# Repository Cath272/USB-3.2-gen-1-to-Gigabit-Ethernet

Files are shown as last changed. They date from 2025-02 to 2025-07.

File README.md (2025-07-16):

# USB 3.2 gen 1 to Gigabit Ethernet
 Gigabit Ethenet to USB C using VL162 and RTL8153

 ## VL162

  - 4:2 10Gbps USB Type-C Data Switch

  - Low power consumption with 6mW active at device mode

 ## RTL8153 

  - Integrated 10/100/1000M transceiver

  - Supports USB 3.0, 2.0, and 1.1

 ###  Built-in Voltage Regulators

- 5.0V to 3.3V LDO

- 3.3V to 1.2V Switching regulator

 ## TLV70233DBVR

 - 5V to 3.3V LDO for spi flash and leds

 ## W25Q16BVSSIG

 - 16Mbit SPI Flash  

 ## HR911130A
 - RJ45 Port with integrated magnetics 
 - 1000 Base-T Magnetics 

## PCB 
This board uses a 4 layer stackup with a  1.6mm thickness:

- POWER/SIGNAL

- GND
  
- GND
  
- POWER/SIGNAL

High Speed diferential lines need a refrence ground plane so internal planes are ground referance planes for the High speed USB lines

### Schematic:
Schematic
## PCB Screenshots

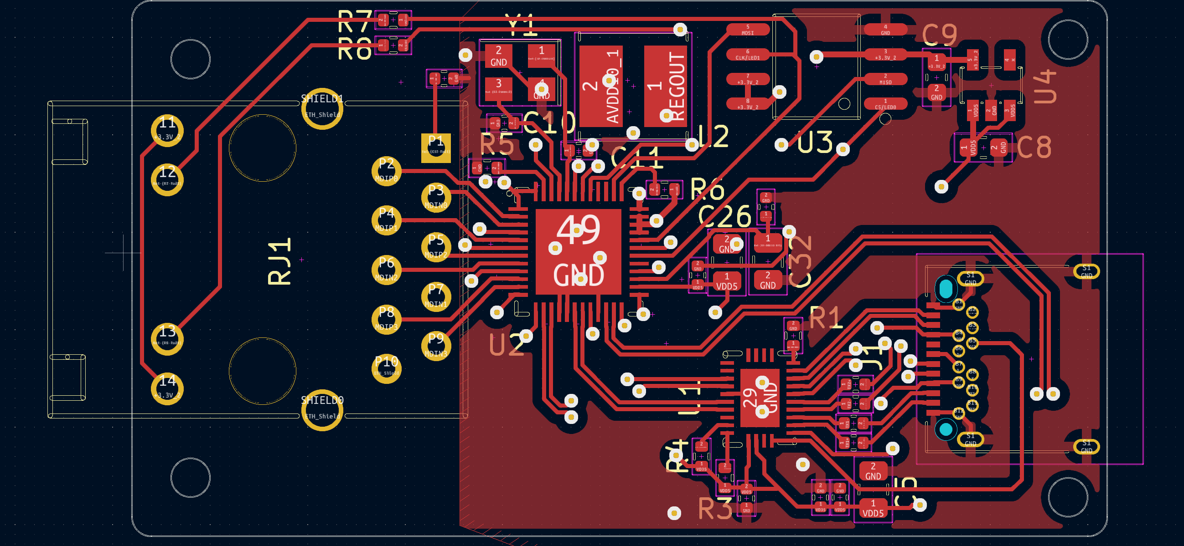
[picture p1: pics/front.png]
usb3ethfront

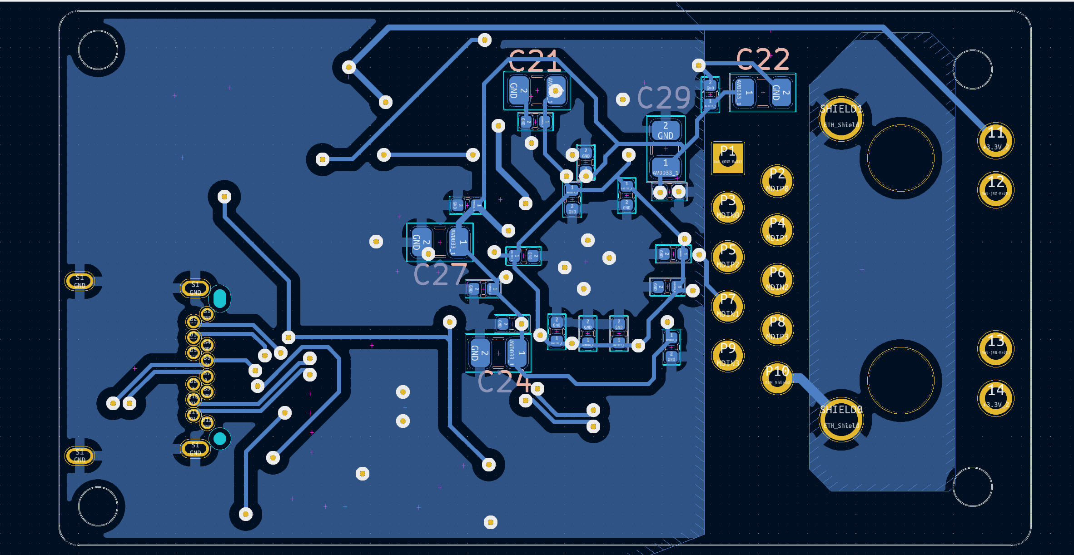
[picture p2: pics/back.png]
usb3ethback

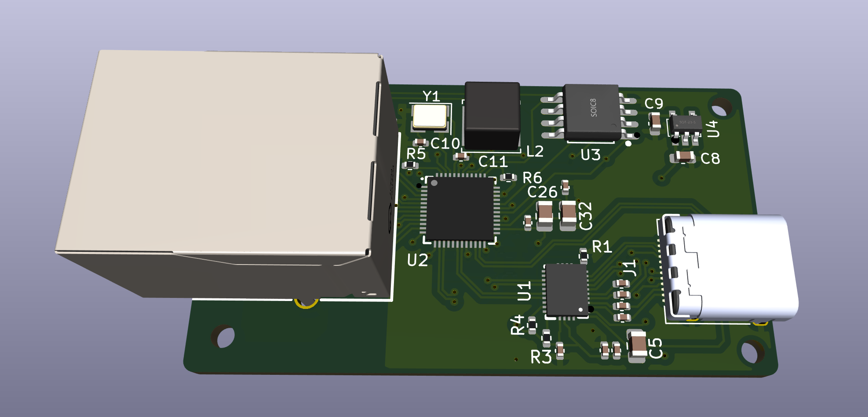
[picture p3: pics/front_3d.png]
usb3ethfront3d

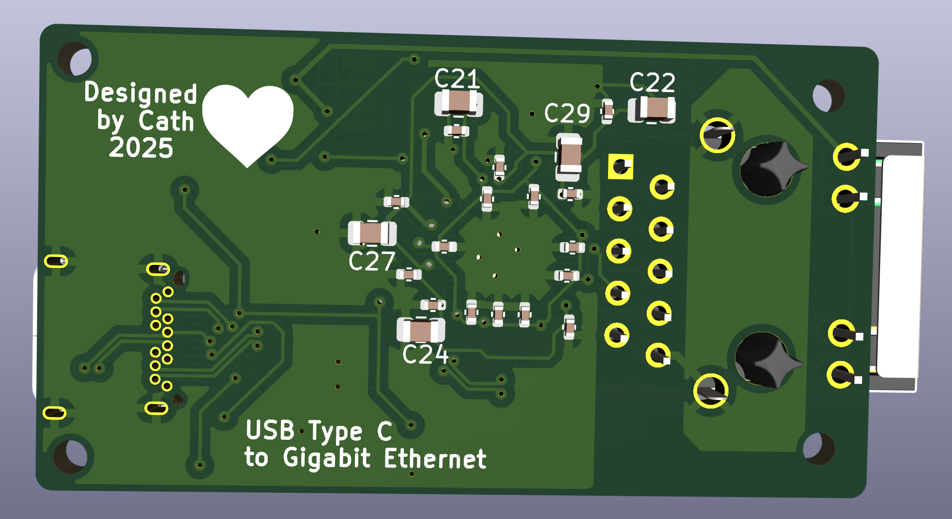
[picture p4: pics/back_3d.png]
usb3ethback3d


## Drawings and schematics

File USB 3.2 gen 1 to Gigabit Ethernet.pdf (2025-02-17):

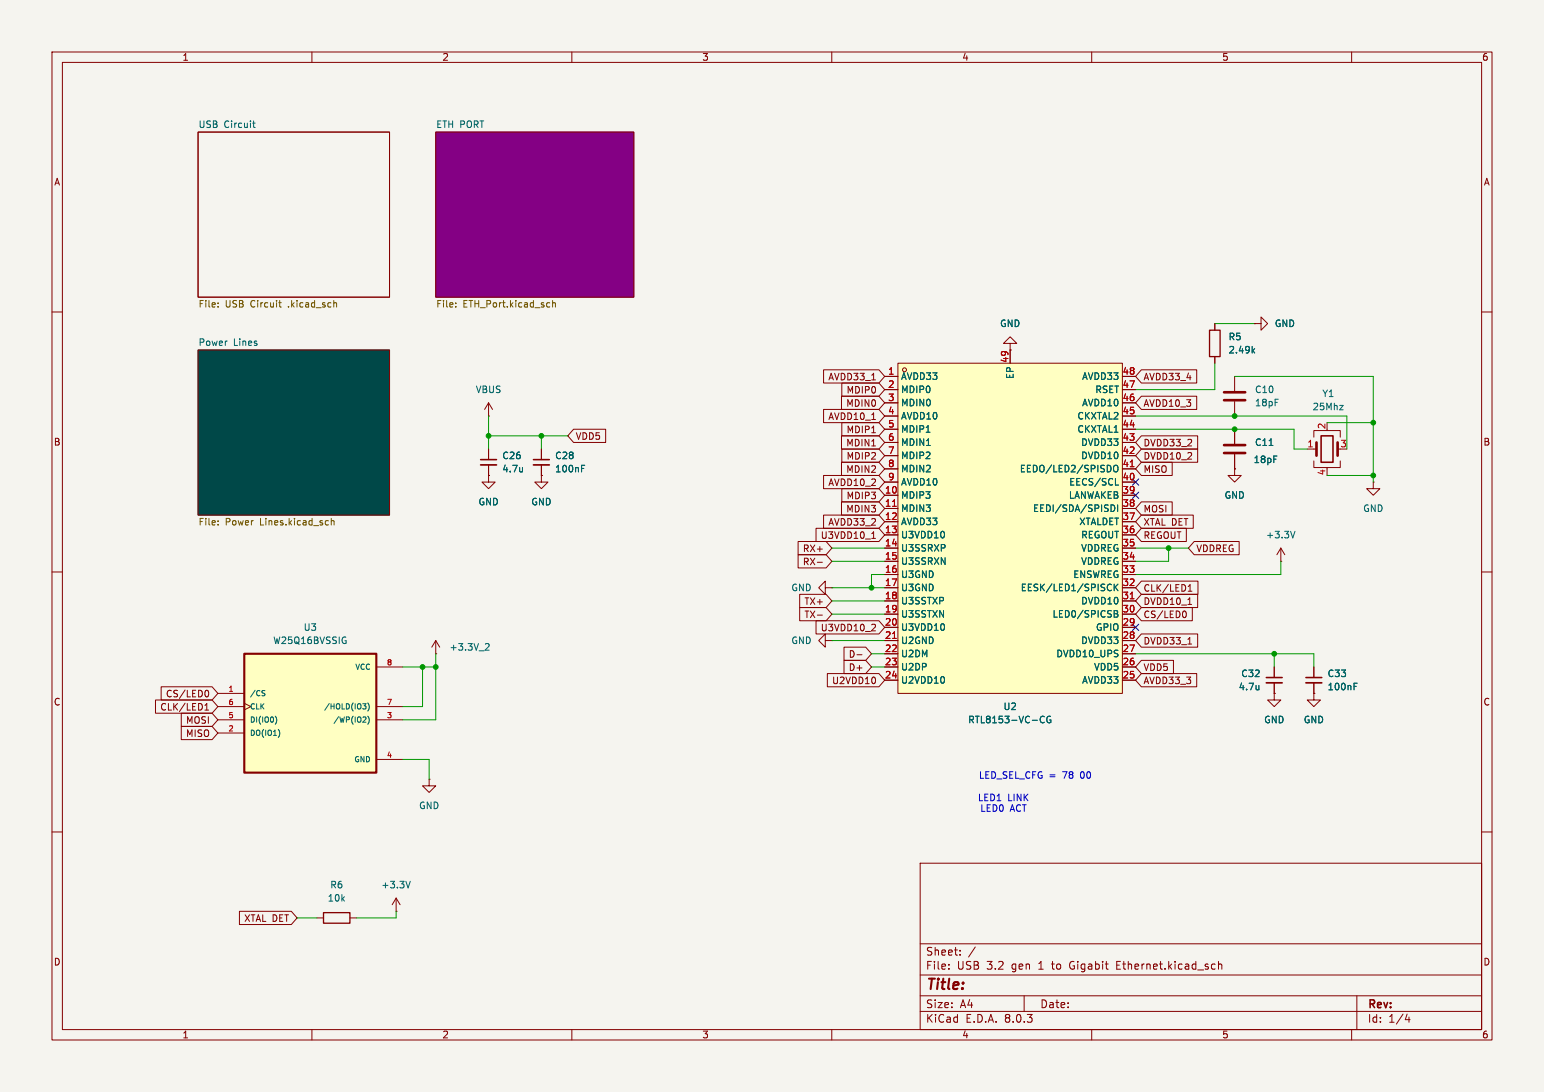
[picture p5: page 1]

AVDD33_4 VDD5 XTAL DET MOSI MISO

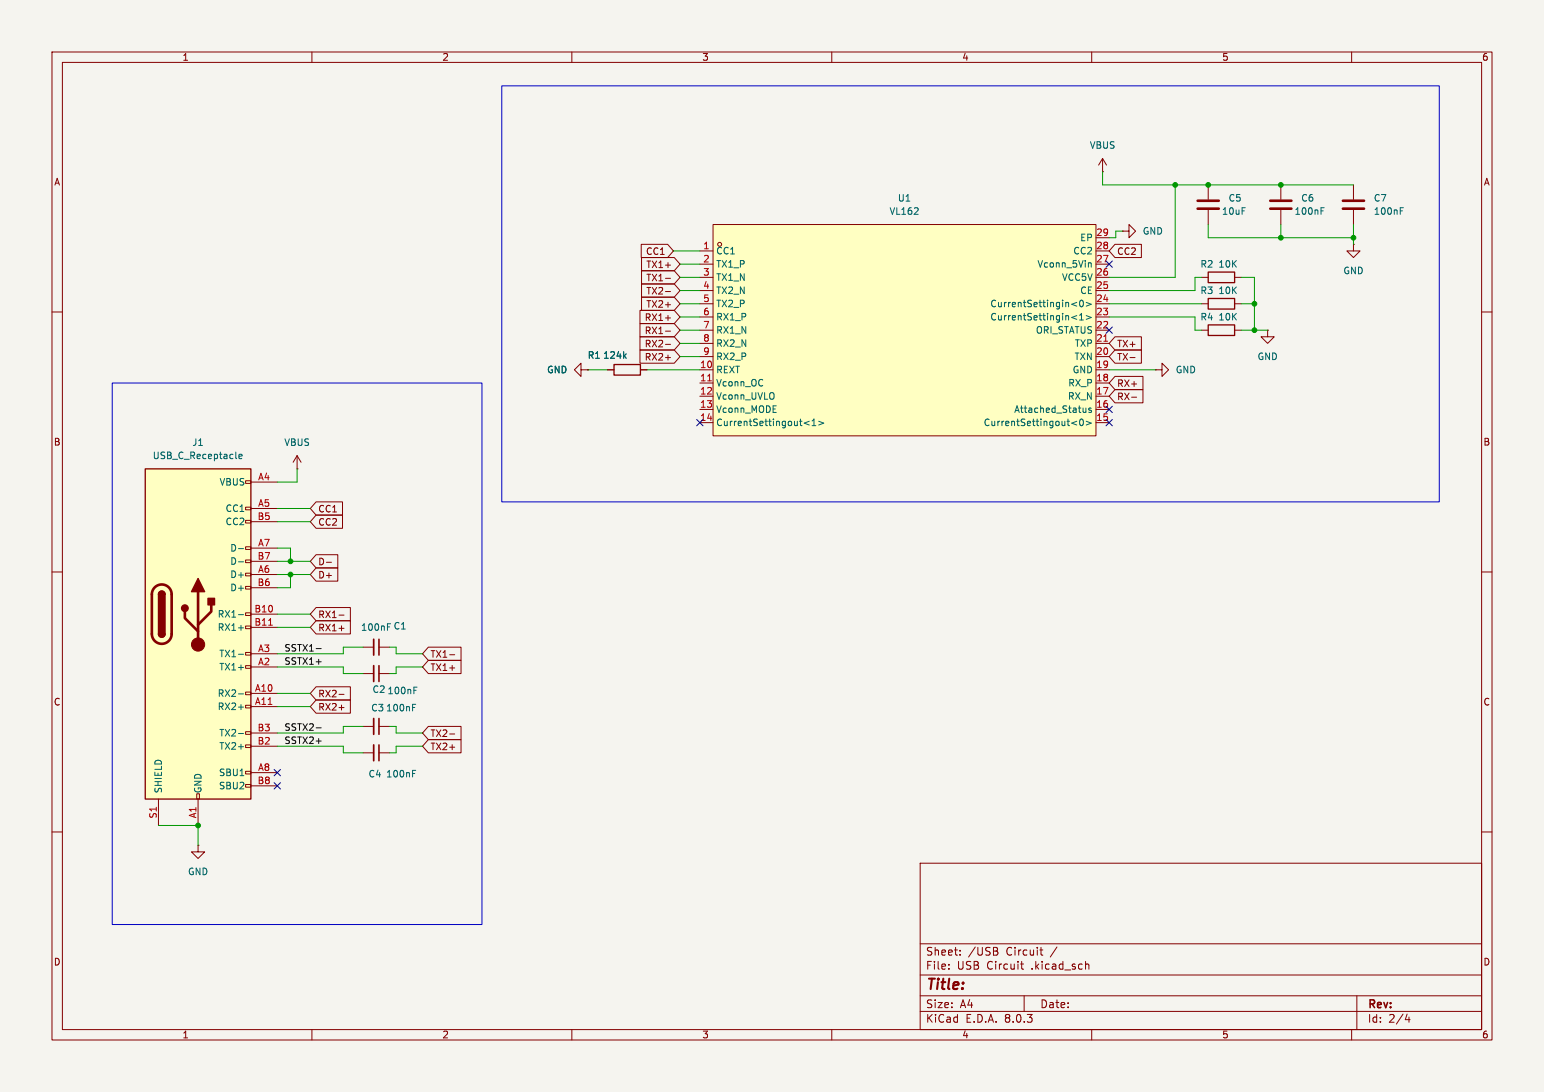
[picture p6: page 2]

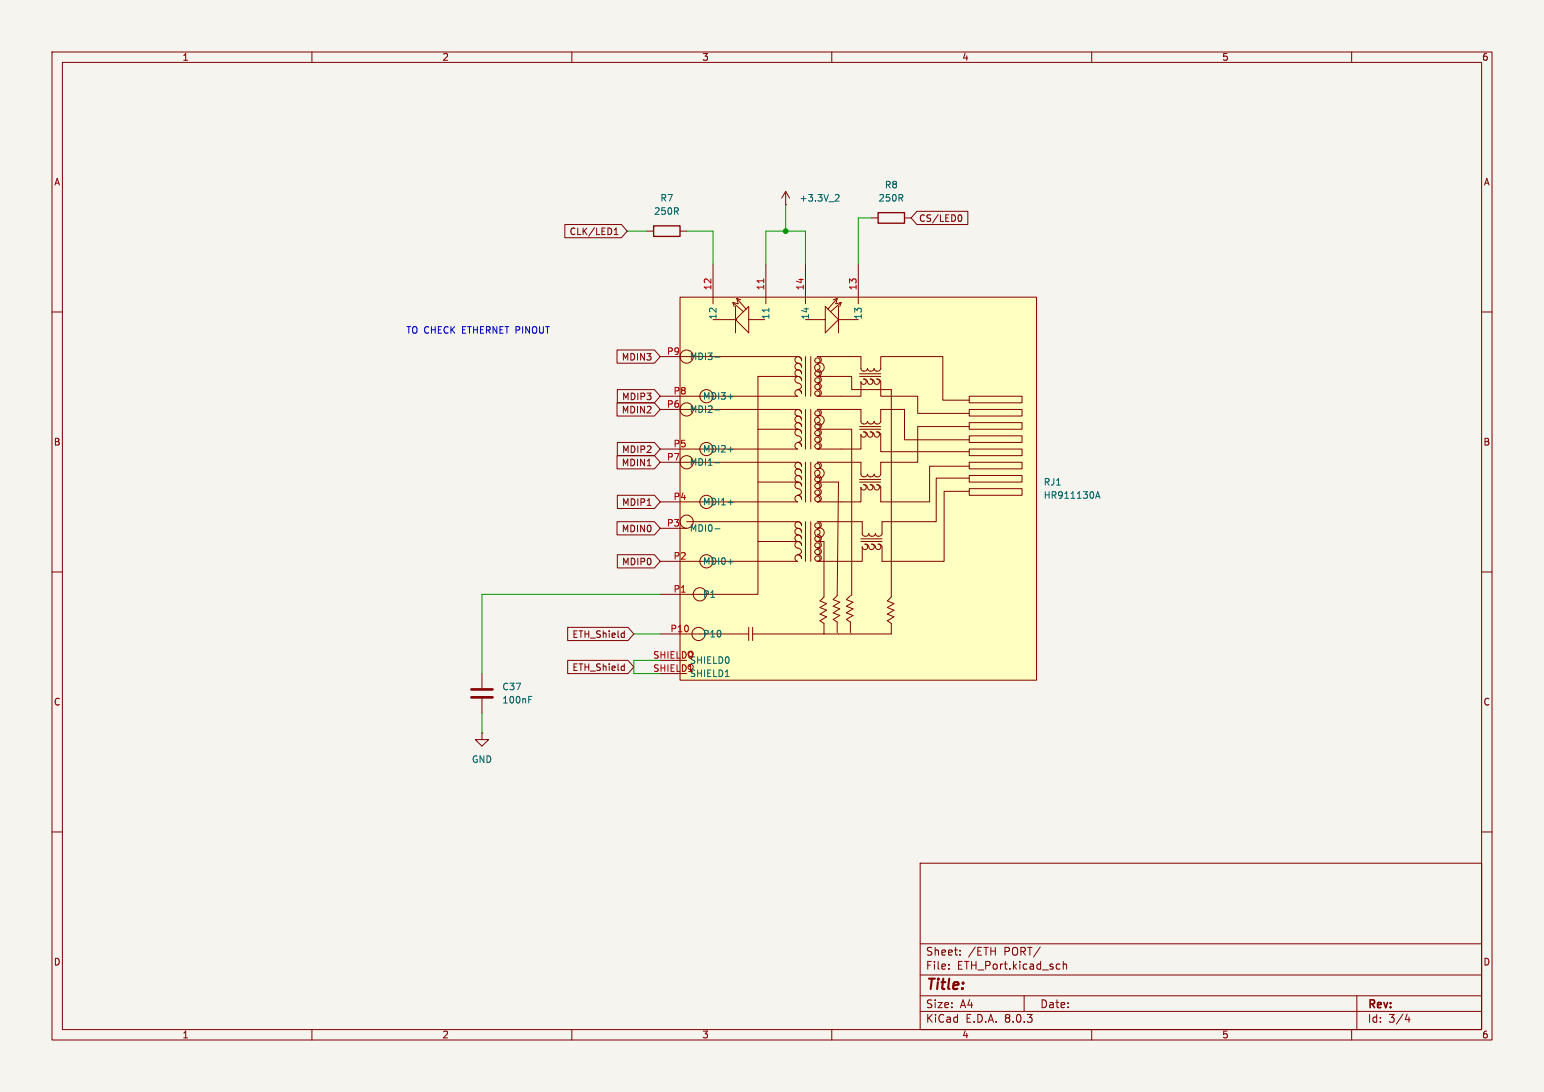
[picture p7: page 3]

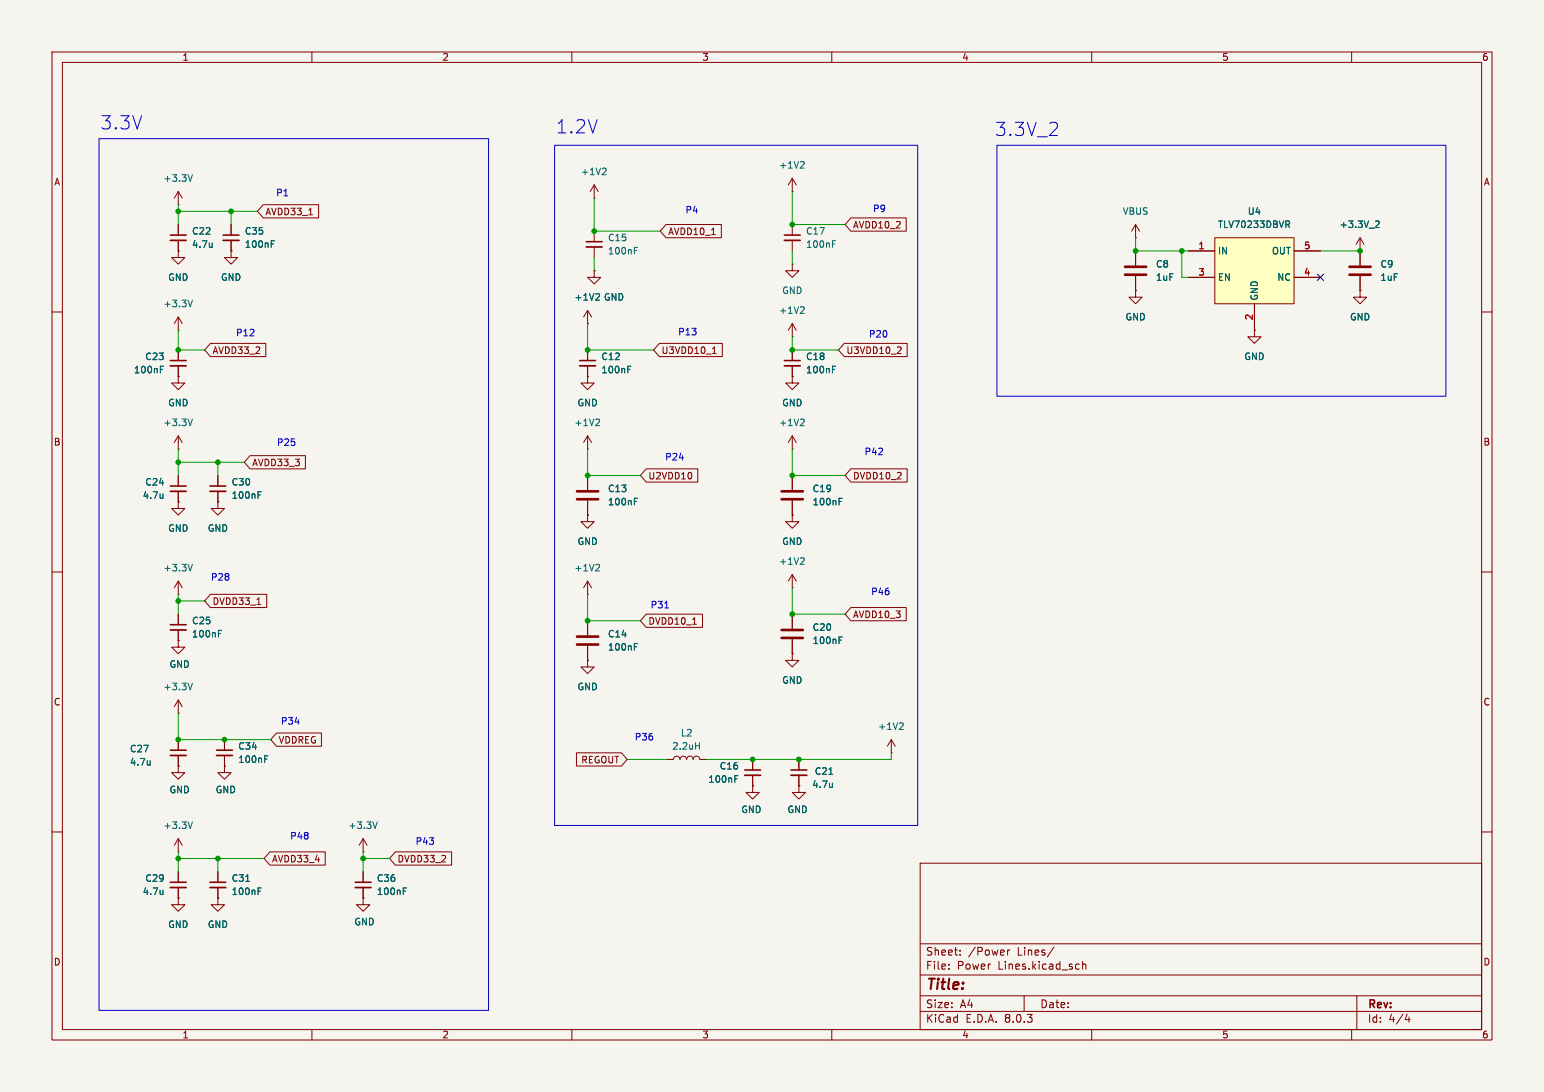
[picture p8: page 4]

2 EN 3 NC 4 OUT 5 GND

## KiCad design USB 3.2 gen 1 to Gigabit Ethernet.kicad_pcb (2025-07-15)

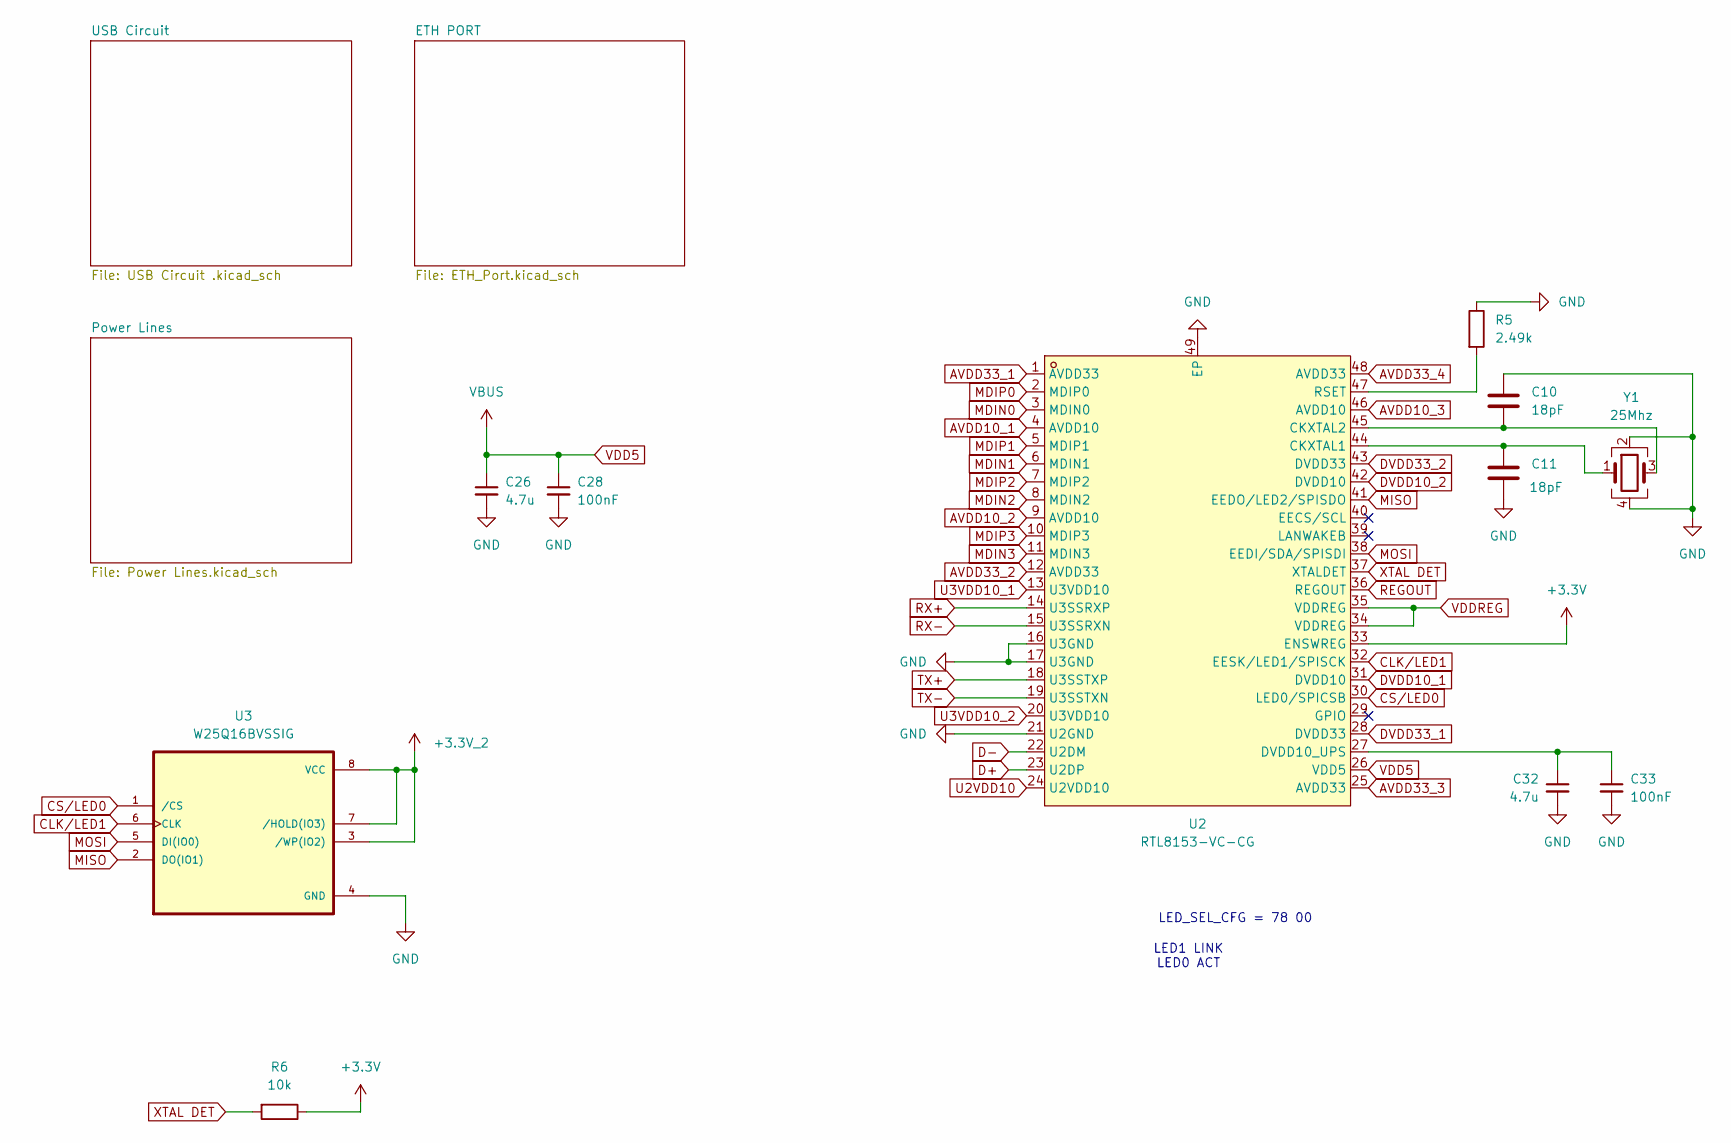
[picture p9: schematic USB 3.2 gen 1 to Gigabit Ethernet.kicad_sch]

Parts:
C10, C11: 18pF; C_0402_1005Metric
C26, C32: 4.7u; C_0805_2012Metric
C28, C33: 100nF; C_0402_1005Metric
R5: 2.49k; R_0402_1005Metric
R6: 10k; R_0402_1005Metric
U2: RTL8153-VC-CG; QFN-48_L6.0-W6.0-P0.40-TL-EP4.4; LCSC Part C2764167
U3: W25Q16BVSSIG; SOIC-8_L5.3-W5.3-P1.27-LS8.0-BL; PARTREV F
Y1: 25Mhz; Crystal_SMD_3225-4Pin_3.2x2.5mm

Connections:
+3.3V_2: U3.3 (/WP(IO2)), U3.7 (/HOLD(IO3)), U3.8 (VCC); also elsewhere on the board
AVDD10_1: U2.4 (AVDD10), U2.9 (AVDD10), U2.13 (U3VDD10), U2.20 (U3VDD10), U2.24 (U2VDD10), U2.31 (DVDD10), U2.42 (DVDD10), U2.46 (AVDD10); also elsewhere on the board
AVDD33_1: R6.1, U2.1 (AVDD33), U2.12 (AVDD33), U2.25 (AVDD33), U2.28 (DVDD33), U2.33 (ENSWREG), U2.34 (VDDREG), U2.35 (VDDREG), U2.43 (DVDD33), U2.48 (AVDD33); also elsewhere on the board
CLK/LED1: U2.32 (EESK/LED1/SPISCK), U3.6 (CLK); also elsewhere on the board
CS/LED0: U2.30 (LED0/SPICSB), U3.1 (/CS); also elsewhere on the board
D+: U2.23 (U2DP); also elsewhere on the board
D-: U2.22 (U2DM); also elsewhere on the board
GND: C10.1, C11.2, C26.2, C28.2, C32.2, C33.2, R5.1, U2.16 (U3GND), U2.17 (U3GND), U2.21 (U2GND), U2.49 (EP), U3.4 (GND), Y1.2, Y1.4; also elsewhere on the board
MDIN0: U2.3 (MDIN0); also elsewhere on the board
MDIN1: U2.6 (MDIN1); also elsewhere on the board
MDIN2: U2.8 (MDIN2); also elsewhere on the board
MDIN3: U2.11 (MDIN3); also elsewhere on the board
MDIP0: U2.2 (MDIP0); also elsewhere on the board
MDIP1: U2.5 (MDIP1); also elsewhere on the board
MDIP2: U2.7 (MDIP2); also elsewhere on the board
MDIP3: U2.10 (MDIP3); also elsewhere on the board
MISO: U2.41 (EEDO/LED2/SPISDO), U3.2 (DO(IO1))
MOSI: U2.38 (EEDI/SDA/SPISDI), U3.5 (DI(IO0))
unnamed: C11.1, U2.44 (CKXTAL1), Y1.1
unnamed: C10.2, U2.45 (CKXTAL2), Y1.3
unnamed: C32.1, C33.1, U2.27 (DVDD10_UPS)
unnamed: R5.2, U2.47 (RSET)
REGOUT: U2.36 (REGOUT); also elsewhere on the board
RX+: U2.14 (U3SSRXP); also elsewhere on the board
RX-: U2.15 (U3SSRXN); also elsewhere on the board
TX+: U2.18 (U3SSTXP); also elsewhere on the board
TX-: U2.19 (U3SSTXN); also elsewhere on the board
VDD5: C26.1, C28.1, U2.26 (VDD5); also elsewhere on the board
XTAL DET: R6.2, U2.37 (XTALDET)

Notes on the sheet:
LED_SEL_CFG = 78 00
LED1 LINK LED0 ACT

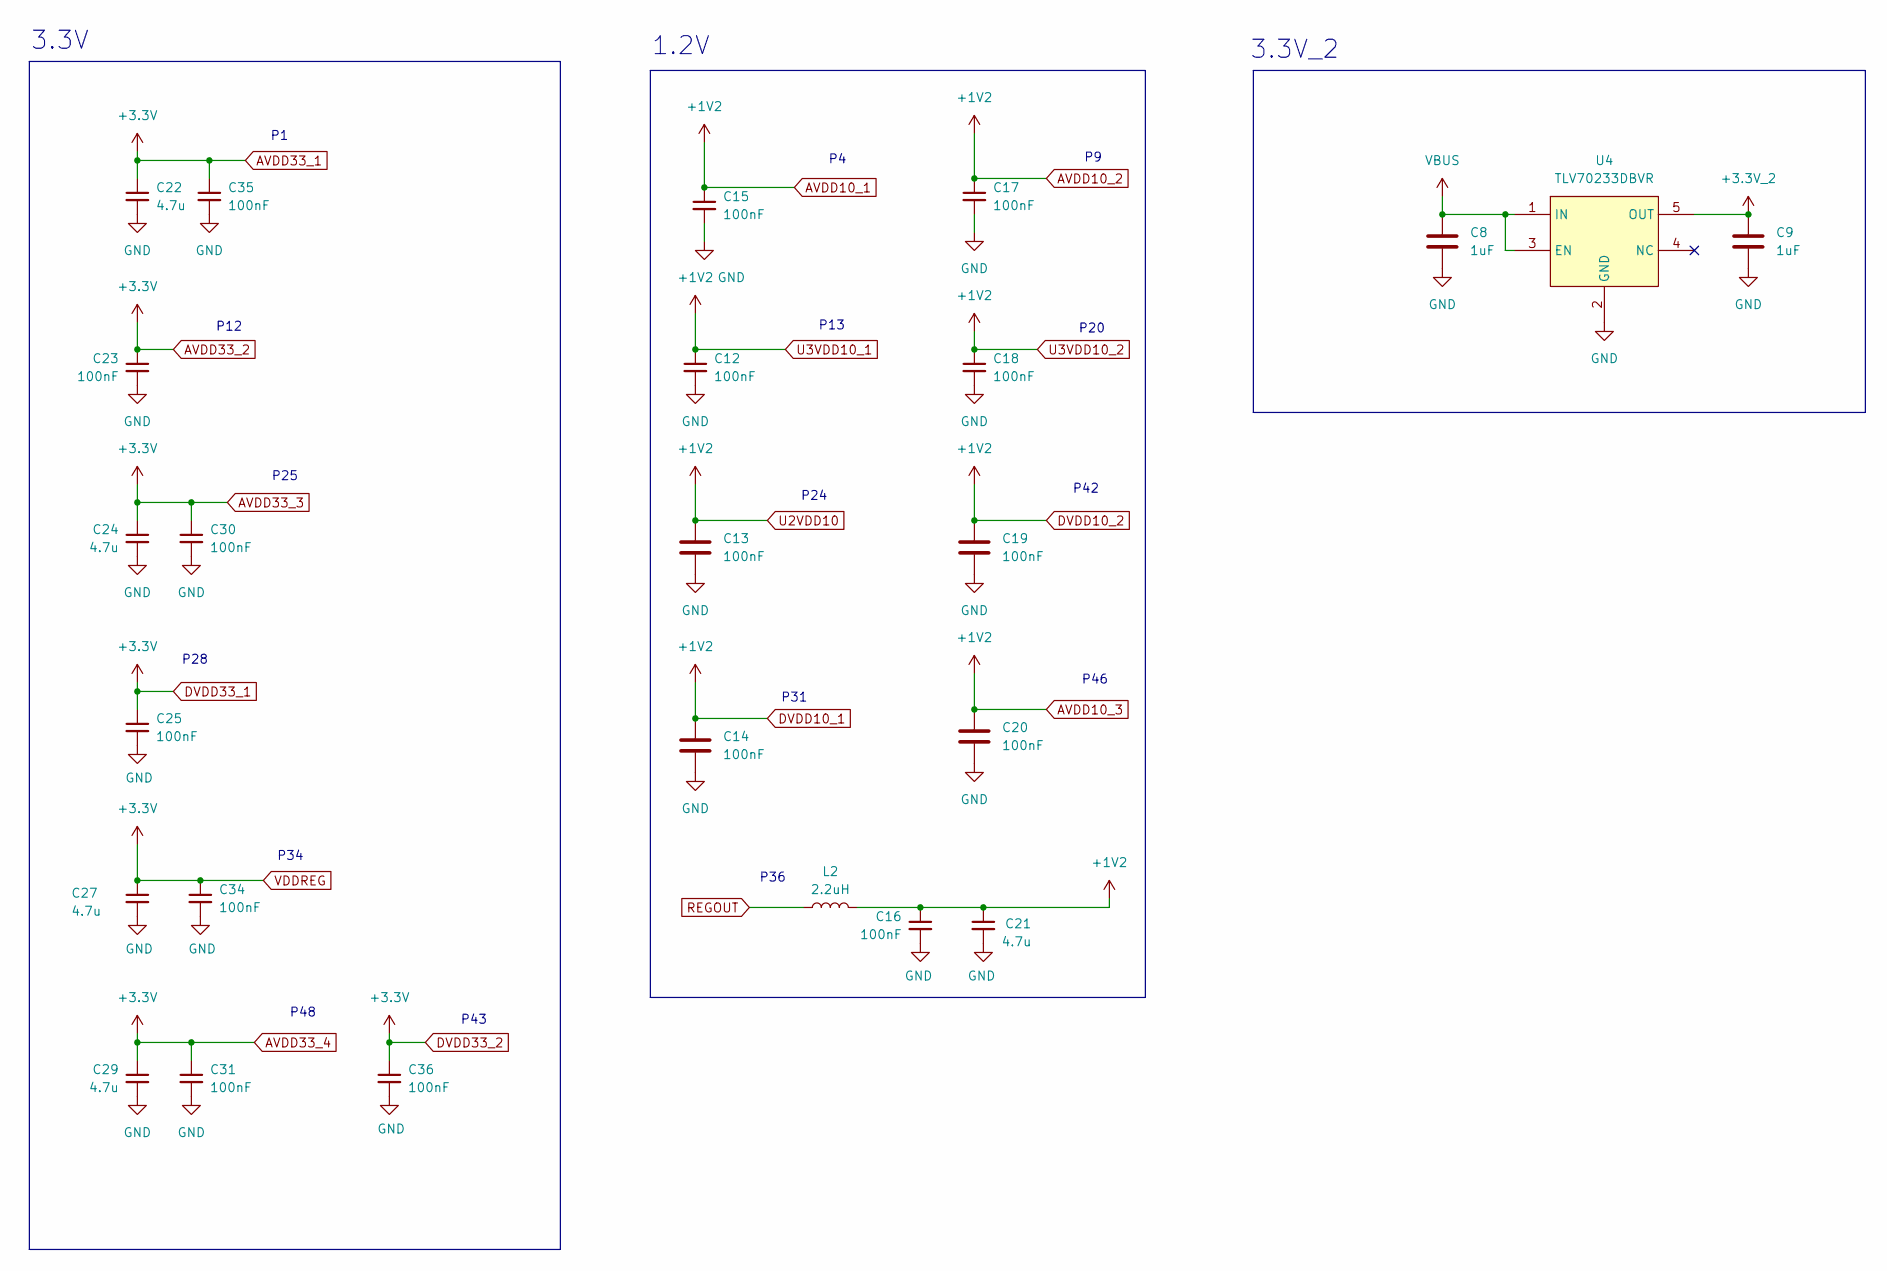
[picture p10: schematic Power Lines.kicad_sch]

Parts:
C8, C9: 1uF; C_0603_1608Metric
C12, C13, C14, C15, C16, C17, C18, C19, C20, C23, C25, C30, C31, C34, C35, C36: 100nF; C_0402_1005Metric
C21, C22, C24, C27, C29: 4.7u; C_0805_2012Metric
L2: 2.2uH; L_Cenker_CKCS5040
U4: TLV70233DBVR; SOT-23-5_L3.0-W1.7-P0.95-LS2.8-BR; LCSC Part C26833

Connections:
+3.3V_2: C9.1, U4.5 (OUT); also elsewhere on the board
AVDD10_1: C12.1, C13.1, C14.1, C15.1, C16.1, C17.1, C18.1, C19.1, C20.1, C21.1, L2.2; also elsewhere on the board
AVDD33_1: C22.1, C23.1, C24.1, C25.1, C27.1, C29.1, C30.1, C31.1, C34.1, C35.1, C36.1; also elsewhere on the board
GND: C8.2, C9.2, C12.2, C13.2, C14.2, C15.2, C16.2, C17.2, C18.2, C19.2, C20.2, C21.2, C22.2, C23.2, C24.2, C25.2, C27.2, C29.2, C30.2, C31.2, C34.2, C35.2, C36.2, U4.2 (GND); also elsewhere on the board
REGOUT: L2.1; also elsewhere on the board
VDD5: C8.1, U4.1 (IN), U4.3 (EN); also elsewhere on the board

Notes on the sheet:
P36
P42
P20
P28
P31
3.3V
P25
P24
P12
P13
1.2V
P48
3.3V_2
P46
P43
P34

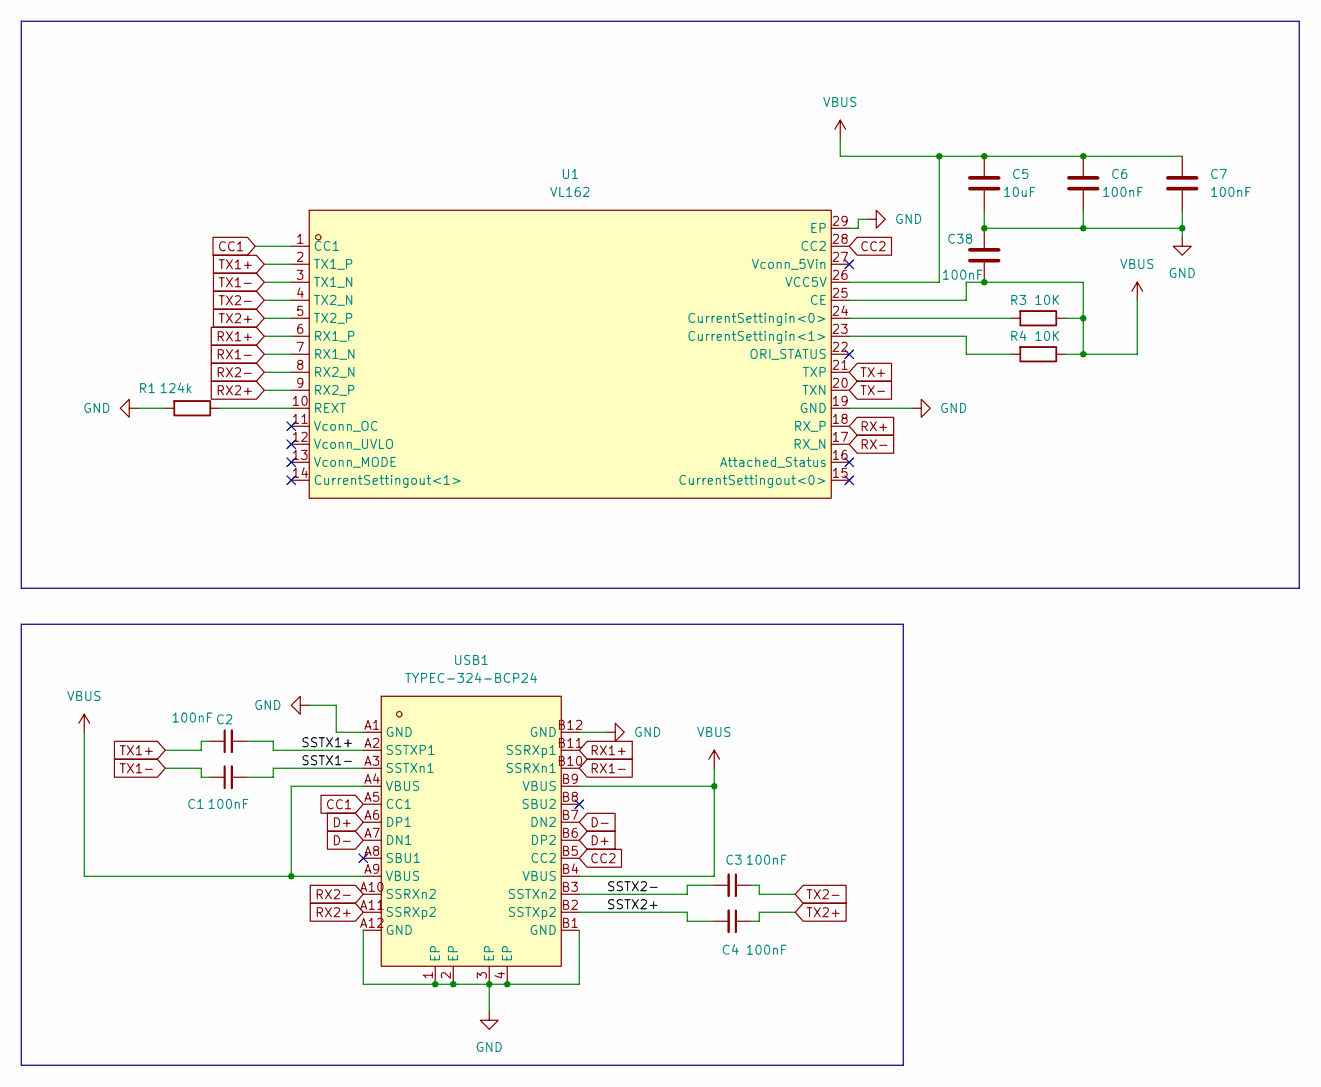
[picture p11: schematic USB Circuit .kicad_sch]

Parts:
C1, C2, C3, C4, C6, C7, C38: 100nF; C_0402_1005Metric
C5: 10uF; C_0805_2012Metric
R1: 124k; R_0402_1005Metric
R3, R4: 10K; R_0402_1005Metric
U1: VL162; MQFN-28_L4.5-W3.5-P0.40-BL-EP; LCSC Part C19270896
USB1: TYPEC-324-BCP24; USB-C-SMD_TYPEC-324-BCP24; LCSC Part C2835314

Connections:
/USB Circuit /SSTX1+: C2.2, USB1.A2 (SSTXP1)
/USB Circuit /SSTX1-: C1.2, USB1.A3 (SSTXn1)
/USB Circuit /SSTX2+: C4.2, USB1.B2 (SSTXp2)
/USB Circuit /SSTX2-: C3.2, USB1.B3 (SSTXn2)
CC1: U1.1 (CC1), USB1.A5 (CC1)
CC2: U1.28 (CC2), USB1.B5 (CC2)
D+: USB1.A6 (DP1), USB1.B6 (DP2); also elsewhere on the board
D-: USB1.A7 (DN1), USB1.B7 (DN2); also elsewhere on the board
GND: C5.2, C6.2, C7.2, C38.1, R1.2, U1.19 (GND), U1.29 (EP), USB1.1 (EP), USB1.2 (EP), USB1.3 (EP), USB1.4 (EP), USB1.A1 (GND), USB1.A12 (GND), USB1.B1 (GND), USB1.B12 (GND); also elsewhere on the board
unnamed: R3.2, U1.24 (CurrentSettingin<0>)
unnamed: R4.2, U1.23 (CurrentSettingin<1>)
unnamed: R1.1, U1.10 (REXT)
RX1+: U1.6 (RX1_P), USB1.B11 (SSRXp1)
RX1-: U1.7 (RX1_N), USB1.B10 (SSRXn1)
RX2+: U1.9 (RX2_P), USB1.A11 (SSRXp2)
RX2-: U1.8 (RX2_N), USB1.A10 (SSRXn2)
RX+: U1.18 (RX_P); also elsewhere on the board
RX-: U1.17 (RX_N); also elsewhere on the board
TX1+: C2.1, U1.2 (TX1_P)
TX1-: C1.1, U1.3 (TX1_N)
TX2+: C4.1, U1.5 (TX2_P)
TX2-: C3.1, U1.4 (TX2_N)
TX+: U1.21 (TXP); also elsewhere on the board
TX-: U1.20 (TXN); also elsewhere on the board
VDD5: C5.1, C6.1, C7.1, C38.2, R3.1, R4.1, U1.25 (CE), U1.26 (VCC5V), USB1.A4 (VBUS), USB1.A9 (VBUS), USB1.B4 (VBUS), USB1.B9 (VBUS); also elsewhere on the board

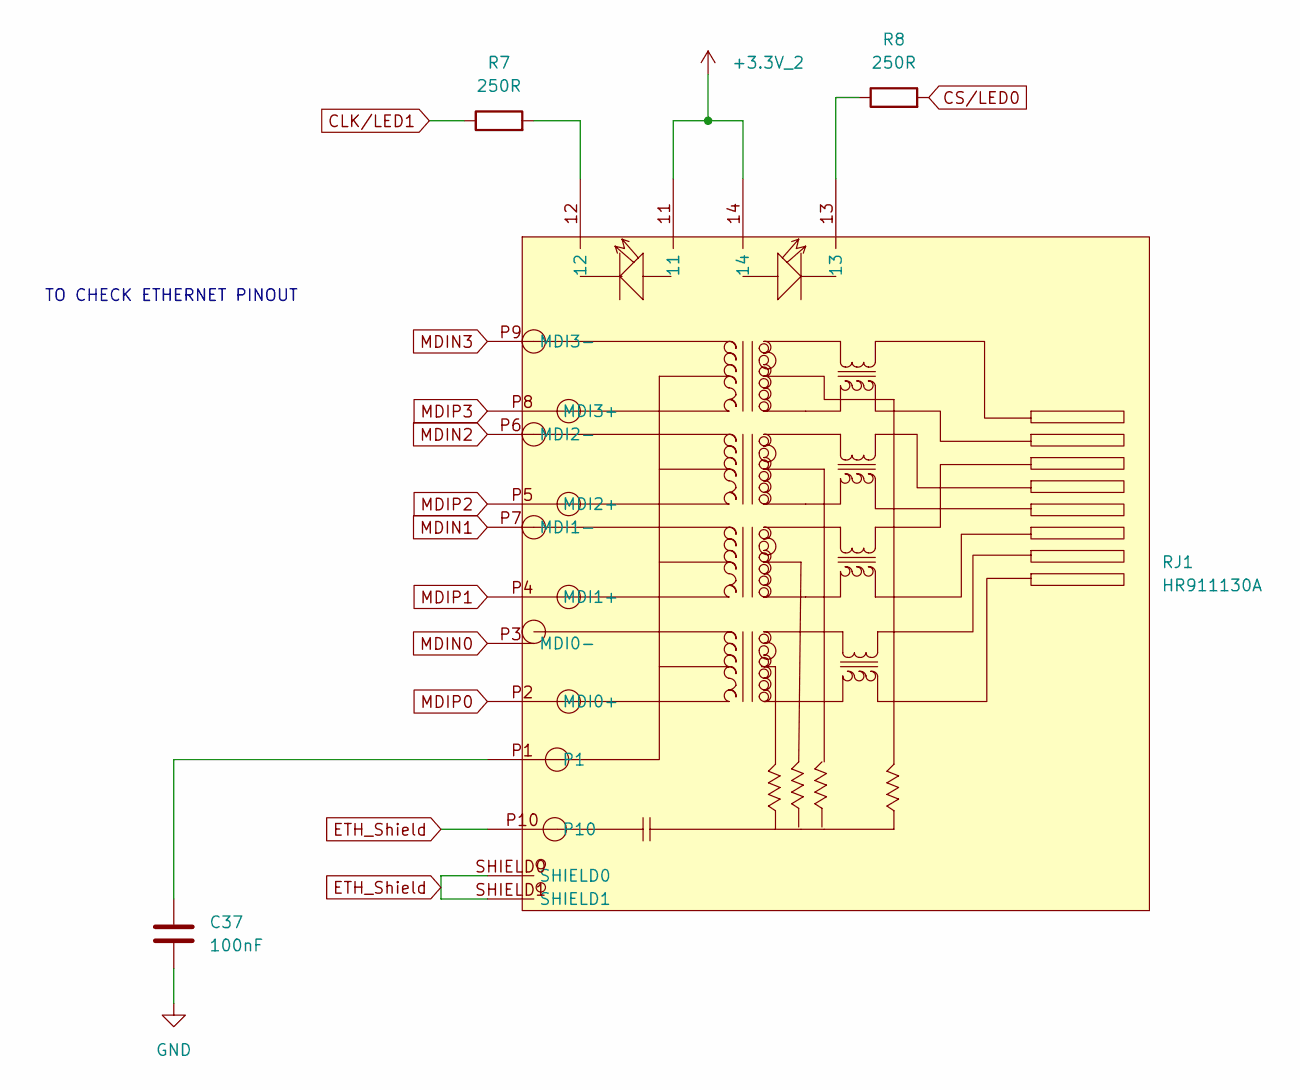
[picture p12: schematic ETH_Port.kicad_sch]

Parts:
C37: 100nF; C_0402_1005Metric
R7, R8: 250R; R_0402_1005Metric
RJ1: HR911130A; RJ45-TH_HR911130A; LCSC Part C54408

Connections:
+3.3V_2: RJ1.11, RJ1.14; also elsewhere on the board
CLK/LED1: R7.1; also elsewhere on the board
CS/LED0: R8.2; also elsewhere on the board
ETH_Shield: RJ1.P10, RJ1.SHIELD0, RJ1.SHIELD1
GND: C37.2; also elsewhere on the board
MDIN0: RJ1.P3 (MDI0-); also elsewhere on the board
MDIN1: RJ1.P7 (MDI1-); also elsewhere on the board
MDIN2: RJ1.P6 (MDI2-); also elsewhere on the board
MDIN3: RJ1.P9 (MDI3-); also elsewhere on the board
MDIP0: RJ1.P2 (MDI0+); also elsewhere on the board
MDIP1: RJ1.P4 (MDI1+); also elsewhere on the board
MDIP2: RJ1.P5 (MDI2+); also elsewhere on the board
MDIP3: RJ1.P8 (MDI3+); also elsewhere on the board
unnamed: C37.1, RJ1.P1
unnamed: R7.2, RJ1.12
unnamed: R8.1, RJ1.13

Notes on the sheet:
TO CHECK ETHERNET PINOUT

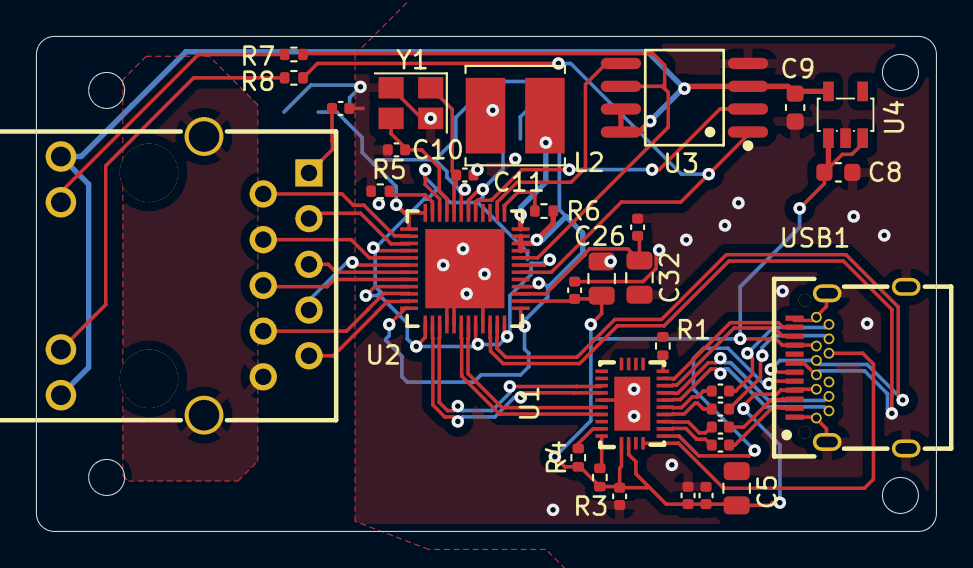
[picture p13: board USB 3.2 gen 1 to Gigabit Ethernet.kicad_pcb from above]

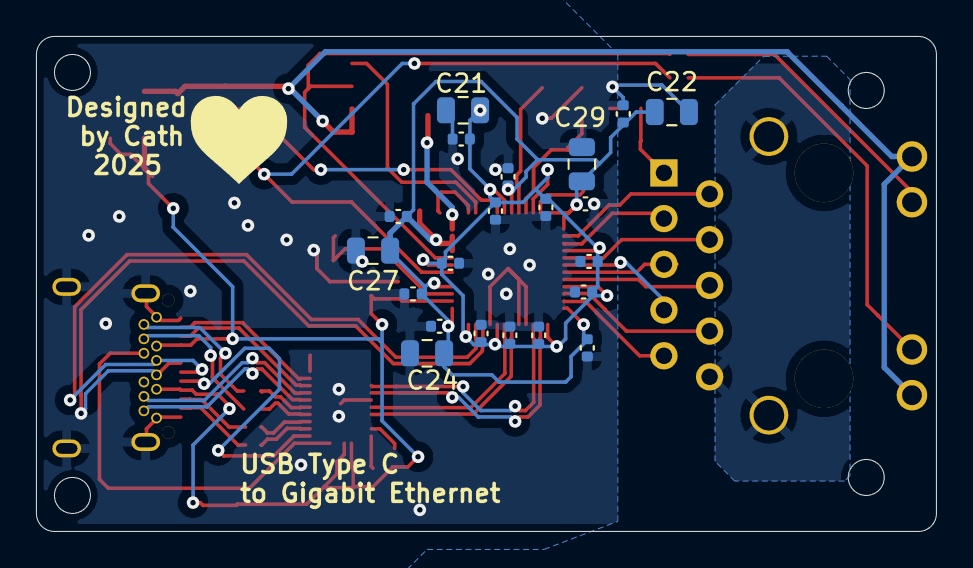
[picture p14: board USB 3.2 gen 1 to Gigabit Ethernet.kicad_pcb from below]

Board: 4 copper layers, 50.0 x 27.5 mm, 53 parts (21 on the bottom side), 50 nets.

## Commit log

2025-02-17 Initial release
    [ETH_Port.kicad_sch, Power Lines.kicad_sch, USB 3.2 gen 1 to Gigabit Ethernet.kicad_pcb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]
2025-02-18 Uploaded pics
    [USB 3.2 gen 1 to Gigabit Ethernet.kicad_pcb]
2025-02-18 updated gerber
2025-02-21 Fixed usb footprint
    [USB 3.2 gen 1 to Gigabit Ethernet.kicad_pcb, USB Circuit .kicad_sch]
